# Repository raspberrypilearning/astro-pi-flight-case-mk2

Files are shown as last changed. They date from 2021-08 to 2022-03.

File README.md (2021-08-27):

# astro-pi-flight-case-mk2

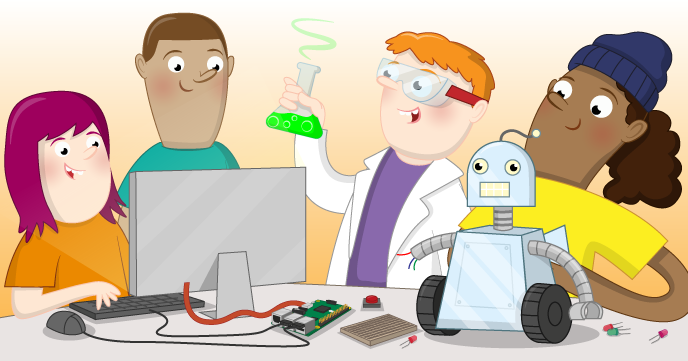
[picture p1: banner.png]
astro-pi-flight-case-mk2


Find the project online at [projects.raspberrypi.org/en/projects/astro-pi-flight-case-mk2](https://projects.raspberrypi.org/en/projects/astro-pi-flight-case-mk2)

## Resources
For project materials and solutions, see [en/resources](https://github.com/raspberrypilearning/astro-pi-flight-case-mk2/tree/master/en/resources) and [en/solutions](https://github.com/raspberrypilearning/astro-pi-flight-case-mk2/tree/master/en/solutions).

## Contributing
See [CONTRIBUTING.md](CONTRIBUTING.md)

## Licence
 See [LICENCE.md](LICENCE.md)

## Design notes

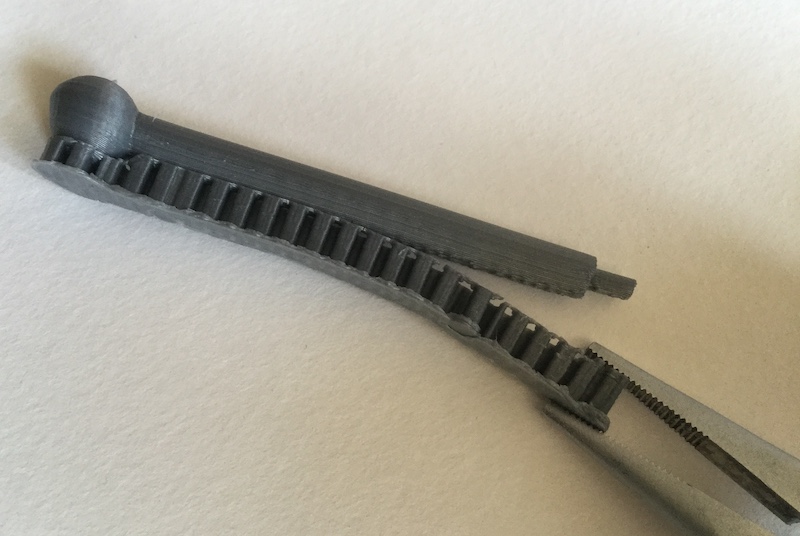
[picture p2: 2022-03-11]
en/images/leg_peel.jpg

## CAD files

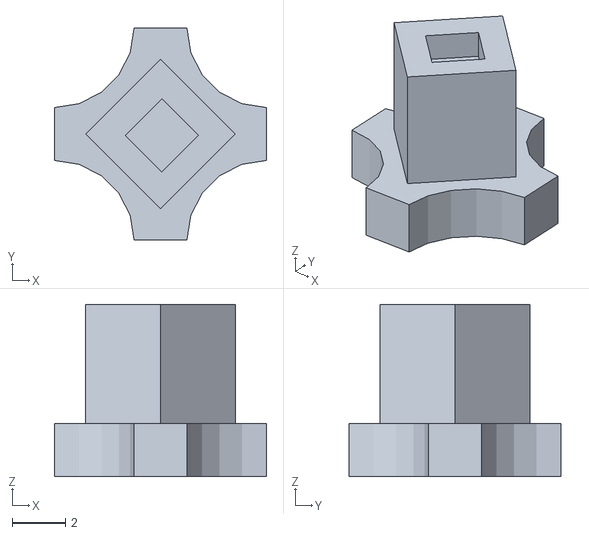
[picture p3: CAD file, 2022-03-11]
en/resources/Astro_Pi_Mark_II_joystick_cap.stl
8.00 x 8.00 x 6.50

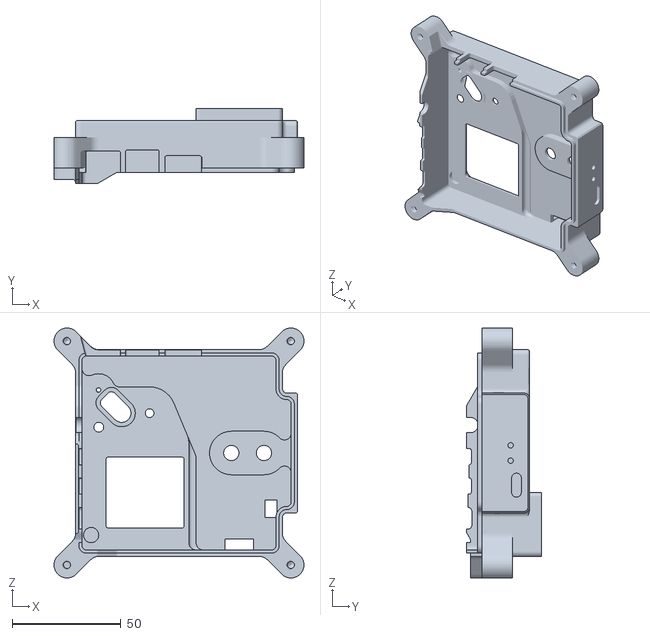
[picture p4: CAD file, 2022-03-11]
en/resources/Astro_Pi_Mark_II_upper_parallax_small_buttons_1.STL
114.8 x 34.7 x 114.8

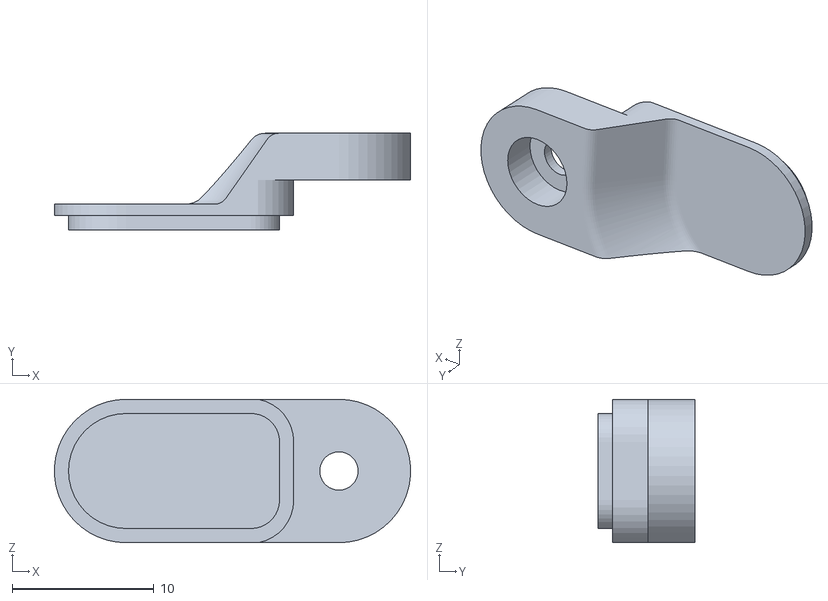
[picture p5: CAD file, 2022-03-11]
en/resources/Astro_Pi_Mark_II_window_1.STL
25.1 x 6.80 x 10.1

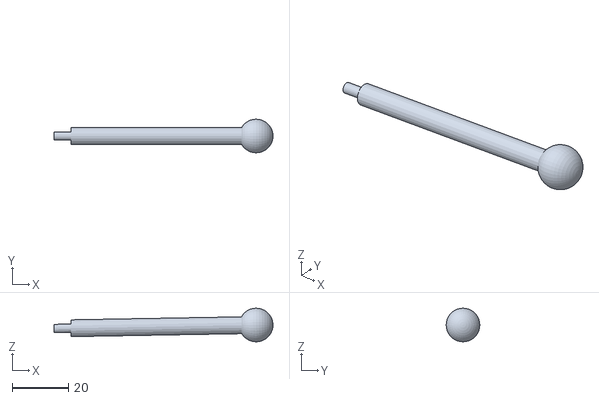
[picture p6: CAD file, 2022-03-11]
en/resources/Astro_Pi_Mark_II_leg.stl
78.0 x 12.0 x 12.0

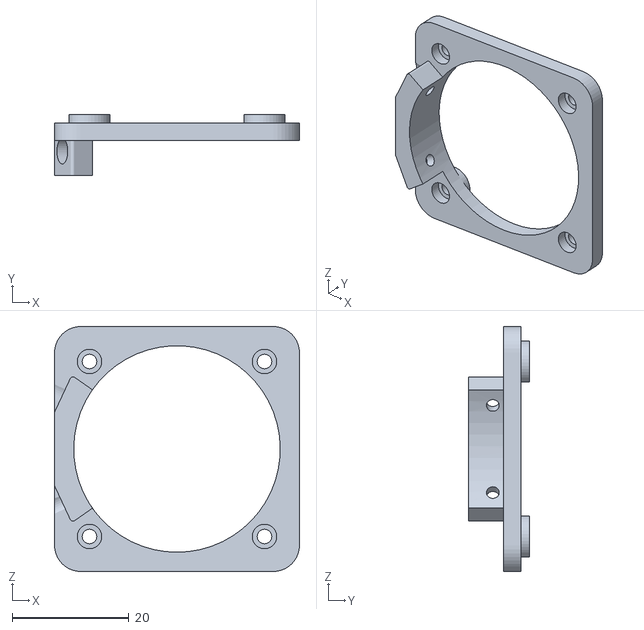
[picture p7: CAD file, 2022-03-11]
en/resources/Astro_Pi_Mark_II_camera_1.STL
42.0 x 10.4 x 42.0

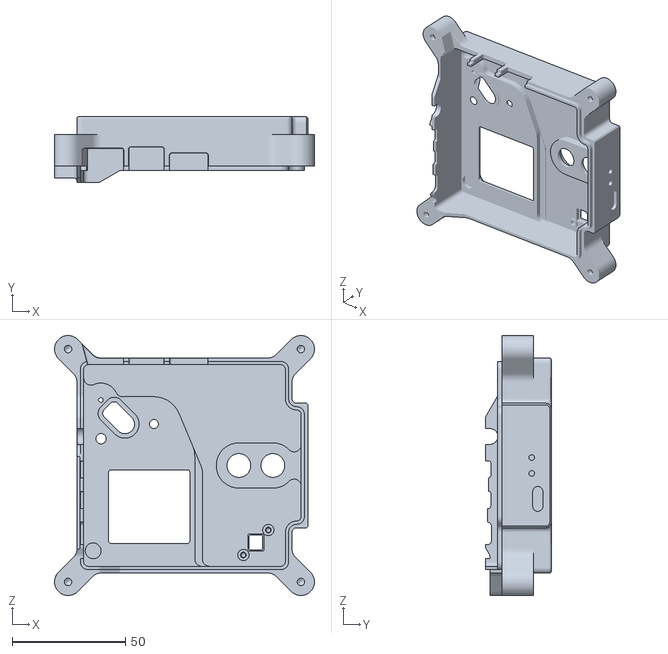
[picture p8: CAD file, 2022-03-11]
en/resources/Astro_Pi_Mark_II_upper_kemet_1.STL
114.8 x 29.0 x 114.8

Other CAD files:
en/resources/Astro_Pi_Mark_II_upper_parallax_1.STL
en/resources/Astro_Pi_Mark_II_upper_kemet_small_buttons_1.STL

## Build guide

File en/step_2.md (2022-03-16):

## Get the 3D files

The 3D files are in [STL](https://en.wikipedia.org/wiki/STL_%28file_format%29){:target="_blank"} format, which is widely used in 3D printing all over the world. If you import them using metric millimetres (mm), no scale adjustments will be required.

If you want to reproduce an authentic copy of the Astro Pi Flight Cases, you'll want to use one of the Kemet PIR sensors that is included on the ISS devices.

However, if you're wanting to build a Flight Case for your Astro Pi Mission Space Lab kit, then you may wish to use the modified STL files that have been produced to allow you to easily fit the Parallax PIR sensor (which is supplied in the kit) to the front panel. 

This means that there are four different options for the front panel: each sensor option has two possible button sizes. Make sure you download and print the right one for your project.

Please note that these STL files are licensed under a [Creative Commons Attribution-NonCommercial-ShareAlike 4.0 International License](https://creativecommons.org/licenses/by-nc-sa/4.0/).



--- task ---

Download each of these files and save them to a folder on your computer:

--- /task ---

**Part 1: Flight Unit front panel**

Here is the standard case front panel, like the ones on the ISS. It has a square hole in the top-right corner **for the Kemet PIR sensor**.

Version 1:  10mm button holes, for use with the buttons used on the ISS Flight Units

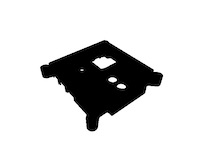
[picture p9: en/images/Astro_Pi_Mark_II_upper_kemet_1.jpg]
Astro_Pi_Mark_II_upper_kemet_1


[Astro_Pi_Mark_II_upper_kemet_1](resources/Astro_Pi_Mark_II_upper_kemet_1.STL) 

Version 2:  7mm button holes

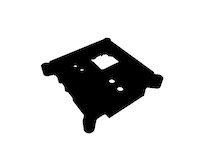
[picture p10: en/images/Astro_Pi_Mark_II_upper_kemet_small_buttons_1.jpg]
Astro_Pi_Mark_II_upper_kemet_small_buttons_1


[Astro_Pi_Mark_II_upper_kemet_small_buttons_1](resources/Astro_Pi_Mark_II_upper_kemet_small_buttons_1.STL) 
  
Here are the modified versions; these have a slot for mounting the larger **Parallax PIR sensor** that is supplied in the official Astro Pi Mission Space Lab entrant kits.

Version 3:  10mm button holes, for use with the buttons used on the ISS Flight Units

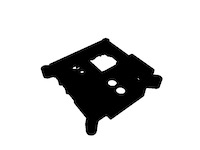
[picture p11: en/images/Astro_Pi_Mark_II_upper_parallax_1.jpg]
Astro_Pi_Mark_II_upper_parallax_1


[Astro_Pi_Mark_II_upper_parallax_1](resources/Astro_Pi_Mark_II_upper_parallax_1.STL) 

Version 4:  7mm button holes

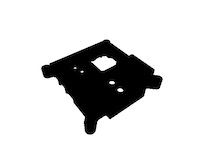
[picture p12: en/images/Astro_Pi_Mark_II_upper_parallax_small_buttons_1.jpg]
Astro_Pi_Mark_II_upper_parallax_small_buttons_1


[Astro_Pi_Mark_II_upper_parallax_small_buttons_1](resources/Astro_Pi_Mark_II_upper_parallax_small_buttons_1.STL) 
  
**Part 2: Flight Unit base**

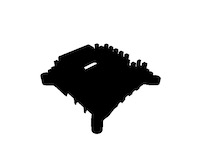
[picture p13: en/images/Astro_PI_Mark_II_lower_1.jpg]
Astro_PI_Mark_II_lower_1


[Astro_PI_Mark_II_lower_1](resources/Astro_PI_Mark_II_lower_1.STL) 

**Part 3: High-Quality Camera sensor mount**

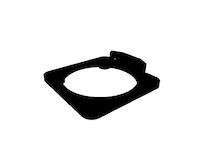
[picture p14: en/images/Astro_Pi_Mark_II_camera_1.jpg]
Astro_PI_Mark_II_camera_1


[Astro_Pi_Mark_II_camera_1](resources/Astro_Pi_Mark_II_camera_1.STL) 

**Part 4: Light sensor window**

The windows on the ISS Flight Units are printed using a transparent resin. This may be difficult to reproduce without a more specialised printer. If you're building a Flight Unit to use with an Astro Pi Mission Space Lab entry kit, we suggest you omit the window so that you can get useful data from the Sense HAT's light sensor. 

If you don't need to use the light sensor, or have an older Sense HAT that doesn't have a light sensor, you could print the window using the same colour filament as the rest of the case, or maybe use a different colour for a custom look. 

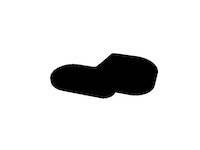
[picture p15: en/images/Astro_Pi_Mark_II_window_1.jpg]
Astro_PI_Mark_II_window_1


[Astro_Pi_Mark_II_window_1](resources/Astro_Pi_Mark_II_window_1.STL) 

**Part 5: Joystick cap**

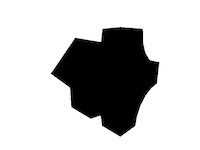
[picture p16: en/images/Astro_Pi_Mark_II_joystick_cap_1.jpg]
Astro_PI_Mark_II_joystick_cap_1


[Astro_Pi_Mark_II_joystick_cap_1](resources/Astro_Pi_Mark_II_joystick_cap.stl)

Note that this joystick cap may need some slight adjustments due to the nozzle size and layer height of your printer. If you have difficulty with fitting it onto the stump of the Sense HAT joystick, then try using a layer height of 0.1mm as opposed to 0.15mm. Because the part is so small, it is also prone to heat warping. The cap was designed using [Tinkercad and you can remix the design](https://www.tinkercad.com/things/9LQoVurYOeM) to precisely adjust the dimensions so that the cap produced by your printer correctly fits the Sense HAT's joystick rod.

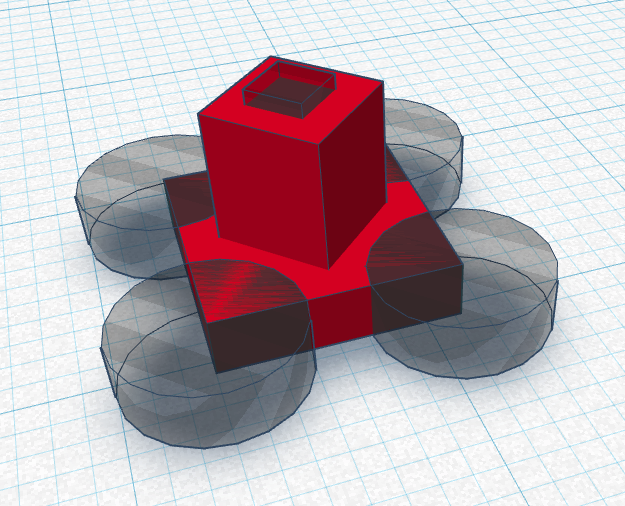
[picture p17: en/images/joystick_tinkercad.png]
Screenshot showing the joystick cap part rendered with Tinkercad.


**Part 6: Legs**

To protect the lens and any window surface against which the Astro Pi may be placed onboard the ISS, the Flight Unit has four removable titanium legs with plastic balls on the end. 

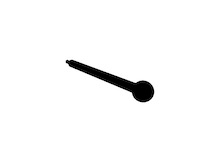
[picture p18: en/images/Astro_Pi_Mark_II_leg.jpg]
Astro_PI_Mark_II_leg


[Astro_Pi_Mark_II_leg](resources/Astro_Pi_Mark_II_leg.stl)

This part is also available for [tweaking and remixing on Tinkercad](https://www.tinkercad.com/things/flDuNtFK9Zh).

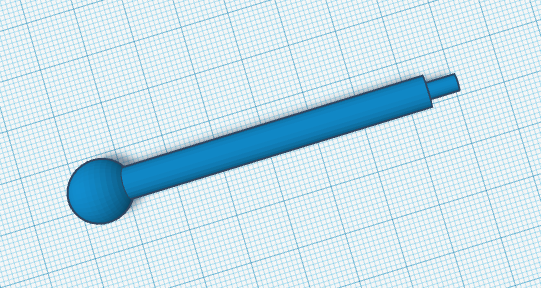
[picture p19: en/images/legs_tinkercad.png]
Screenshot showing the leg part rendered on Tinkercad.


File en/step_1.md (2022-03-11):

## Introduction

The Astro Pi Flight Case is one of the most sought-after cases in the history of the Raspberry Pi. The original Mark I hardware Flight Units have been in operation on the International Space Station (ISS) since 2015. In 2021, new, upgraded Astro Pis were sent as replacements. With the inclusion of a more powerful Raspberry Pi, new sensors, and the Raspberry Pi High-Quality Camera, a new Flight Case design was required. 

In this resource, you will learn how to 3D print your own Astro Pi Mark II Flight Case and install the Astro Pi hardware inside it. You’ll then have your very own Astro Pi Flight Unit, identical in almost every way to the new ones that are now operational on the ISS.

You don't have to follow every step exactly as it is described in this guide, which is intended to provide a reliable set of instructions for someone who would like to produce a replica case. There are often many different ways to tackle projects like this, so if you have another preferred technique, or think that something should be done in a different way, you should go ahead and try an alternative approach. This is particularly true for the 3D printing part of the project: there are lots of different 3D printers and filaments and you should expect to have to modify some of the steps in order to take these differences into account. Please note that this is a complex project and that you should expect to have to tweak your process for best results. Be prepared for print jobs that don’t produce the best possible parts first time. 

### What you will make

--- no-print ---
Here are some examples of how your finished 3D-printed Astro Pi Flight Cases might look:

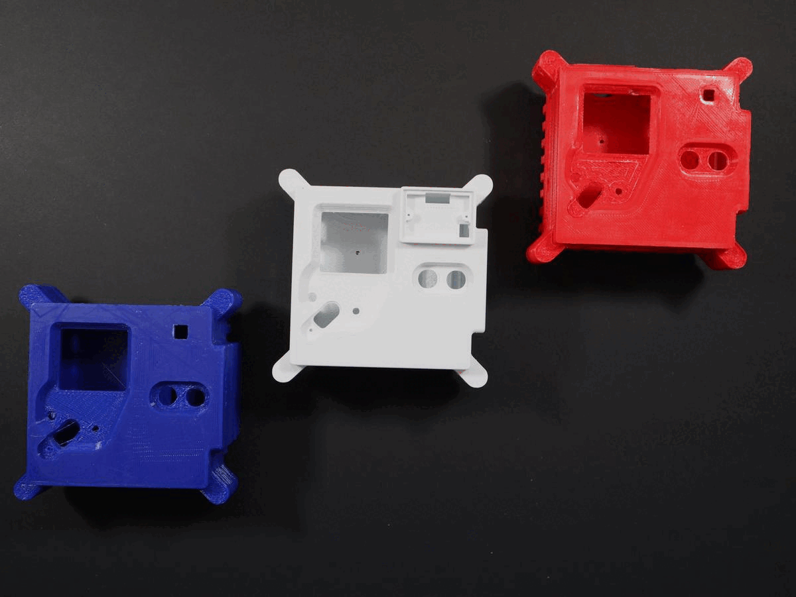
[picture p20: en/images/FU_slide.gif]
A series of images showing several 3D-printed Flight Cases, with different colours, buttons, and one with legs.


--- /no-print ---

--- print-only ---
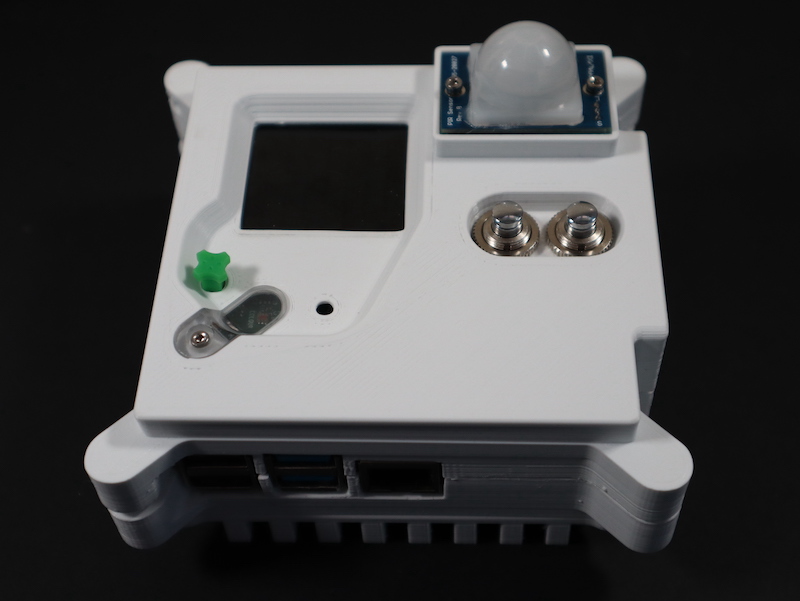
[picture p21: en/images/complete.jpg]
A photo of the completed Flight Case.

--- /print-only ---

--- collapse ---
---
title: What you will need
---
### Hardware

+ [Raspberry Pi 4](https://www.raspberrypi.com/products/raspberry-pi-4-model-b/) and SD card
+ [Raspberry Pi High-Quality Camera](https://www.raspberrypi.com/products/raspberry-pi-high-quality-camera/) 
+ [Raspberry Pi Sense HAT](https://www.raspberrypi.com/products/sense-hat/)
+ 2 Push buttons (either 10mm diameter thread or 7mm — see below)
+ [Kemet](https://uk.farnell.com/kemet/ss-430l-w/pir-sensor-5m-37deg-28deg-5-5vdc/dp/3027688) or [Parallax](https://www.parallax.com/product/pir-sensor-with-led-signal/) Passive Infrared (PIR) sensor (as supplied in the official Mission Space Lab kits)
+ If using the Kemet PIR sensor, you'll also need the [right cable](https://www.digikey.co.uk/en/products/detail/jst-sales-america-inc/A05SR05SR30K152B/6708507)
+ If using the Parallax PIR sensor, you'll need a three-segment electrical connector block
+ M2.5/M2.5 × 11mm × 5mm M/F threaded hexagon spacers 
+ M2.5/M2.5 × 10mm × 5mm M/F threaded hexagon spacers 
+ [26-Pin tall header](https://thepihut.com/products/stacking-header-for-raspberry-pi-2x13-extra-tall)
+ M2.5 × 6mm full thread cap head screws (DIN 912) 
+ M2 X 16mm cap head screws (DIN 912) 
+ M2 Hexagon Nuts (DIN 934) - Stainless Steel 
+ M4 × 12mm full thread cap head screws (DIN 912)
+ M2 × 8mm full thread cap head screws (DIN 912) 
+ 7 Short (approx. 120mm) jumper wires, with one end F
+ Some 2mm diameter heat shrink tubing
+ A 90 × 50mm strip of [Rosco 98 medium grey filter film](https://us.rosco.com/en/products/filters/r98-medium-grey) 

If you want to buy the [exact buttons](https://www.mouser.co.uk/datasheet/2/26/pusbutton-switches-serie-10400-1519227.pdf) used in the Astro Pi Flight Unit, the details are below. However, they are expensive — that's because they're designed to survive an enormous number of clicks before wearing out, a feature that is necessary for a five-year space mission.

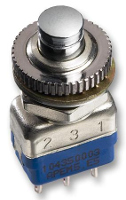
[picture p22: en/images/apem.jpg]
Astro Pi actual button.


- Manufacturer: APEM
- Manufacturer Part No: 104350003

If you want to use different (cheaper) buttons, then go ahead. We have two different versions of the top panel of the flight unit, one for 10mm buttons, one for 7mm. You should decide on your choice of buttons before printing your case!

### Additional requirements

+ Access to a 3D printer. Many schools now have their own, or you might be able to find one at your local [Makerspace](http://www.hackspace.org.uk/){:target="_blank"}. You can also find local 3D printing services through the [3D Hubs website](https://www.3dhubs.com/){:target="_blank"}.

You’re also going to need the following tools:

+ 1.5mm Allen key
+ 2.5 Allen key
+ Small pair of pliers
+ Craft knife or scalpel
+ Sandpaper
+ Scissors
+ Sticky tape
+ Wire strippers
+ Wire cutters
+ Soldering iron and solder (if you've never soldered before, have a look at [this video](https://www.raspberrypi.com/news/getting-started-soldering/) for some tips) 
+ Hot air gun

### Software

+ Raspberry Pi OS

### Downloads

+ [Self test software](resources/selftest.zip)

--- /collapse ---

--- collapse ---
---
title: What you will learn
---

+ Techniques to 3D print irregular shapes
+ How to connect electronics to the Raspberry Pi computer using GPIO pins

--- /collapse ---

--- collapse ---
---
title: Additional information for educators
---

If you need to print this project, please use the [printer-friendly version](https://projects.raspberrypi.org/en/projects/projectName/print){:target="_blank"}.

--- /collapse ---

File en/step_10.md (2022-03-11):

## Assemble the case

Once you're happy that the internals of the case are complete, you can proceed to the final assembly stage.

--- task ---

Cut a strip of the grey Rosco filter material 45mm × 90mm and fold it in half. Use two small pieces of tape to attach it to the inside of the top panel, over the LED matrix window. Make sure none of the tape is visible from the outside.

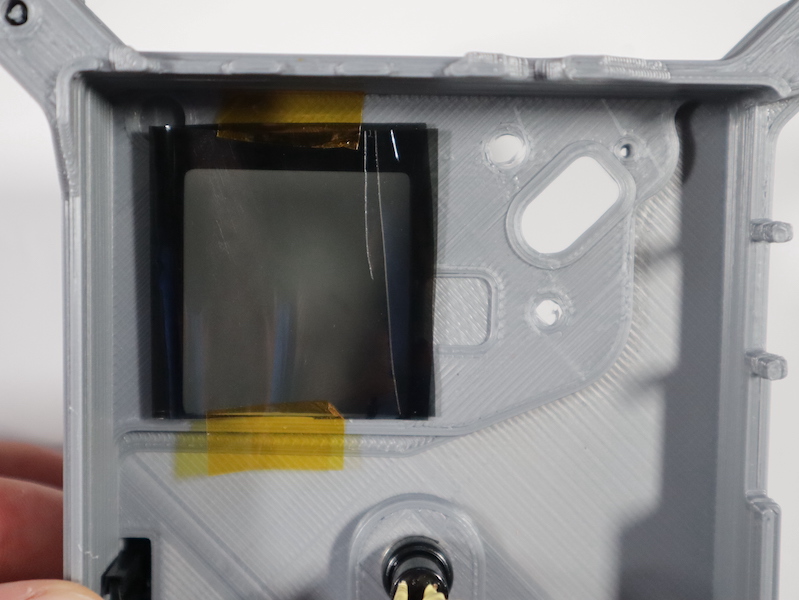
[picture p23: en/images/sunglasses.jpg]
Photo showing the LED matrix filter held in place with two small pieces of tape.


--- /task ---

--- task ---

Take the top panel and gently tuck the wires into the space on the right of the Raspberry Pi as neatly as you can.

--- /task ---

--- task ---

Place the top panel on top of the bottom case part.

--- /task ---

--- task ---

Screw the two case halves together with M4 × 12mm screws.

--- /task ---

--- task ---

Install your 3D-printed joystick cap by pressing it onto the Sense HAT joystick. You will probably need to use glue to keep it in place, but only apply the glue once you've tested everything and are happy that it all works. The Astro Pis on the ISS use a 3D-printed cap too!

--- /task ---

--- task ---

Fit the four legs into the holes on the rear panel. You may need to use glue to keep them in place, or you can try adjusting the dimensions of the part to optimise the fit for parts printed on your specific printer. 

--- /task ---

Your Astro Pi Flight Unit is almost complete — the last thing to do is to add the colour sensor window. Fit this into the slot and attach it with a M2.5 × 6mm screw.

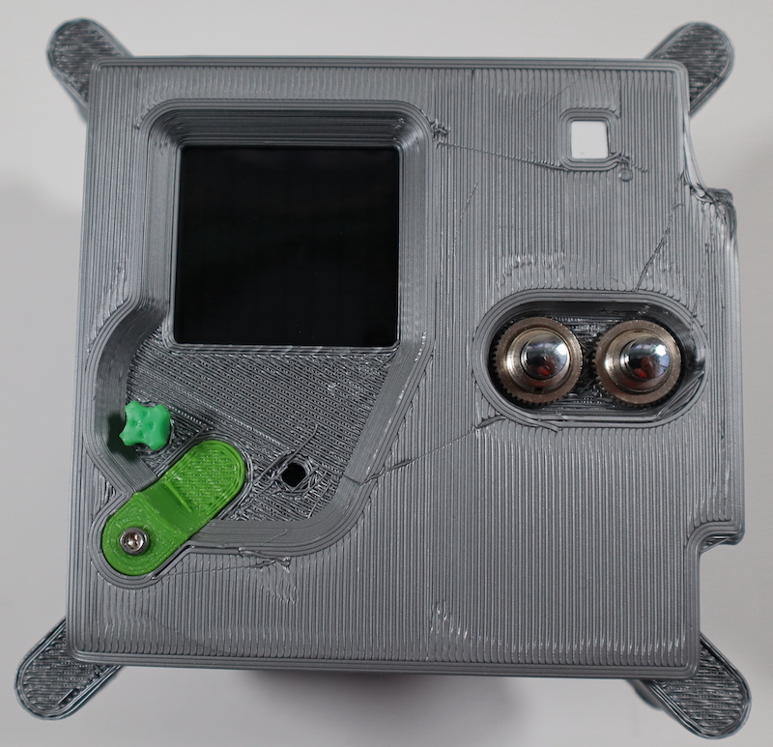
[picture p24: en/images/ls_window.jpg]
A photo of a 3D-printed Flight Unit with a green joystick cap and light sensor window.


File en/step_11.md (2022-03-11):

## Test the hardware

--- task ---

Once you have assembled the Astro Pi, start it up with a monitor, keyboard, and mouse connected.

--- /task ---

For use on the ISS, we created a program that performs a test of the hardware to make sure everything is working. You can download a version of this software to run on your 3D-printed Astro Pi to check your wiring.

--- task ---
[Download the software](resources/selftest.zip) and then open a terminal window and enter these commands:

```bash
unzip selftest.zip
```

--- /task ---

--- task ---
Then run the tests:

```bash
cd selftest
python3 selftest.py --timeout 20
```
A series of tests will begin, some run autonomously whereas others are interactive and require a user to physically manipulate the Astro Pi unit when prompted. If you want longer to complete each test, increase the value supplied as the `timeout` parameter.

Initially, some of the LEDs on the matrix will light up, indicating the outcomes of the diagnostic tests. Then, a series of icons will be displayed to indicate which interactive test is active.

First will be the humidity sensor test. 

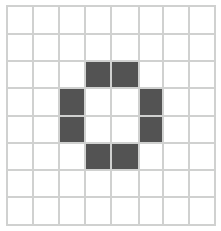
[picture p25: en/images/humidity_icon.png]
The icon for the interactive humidity test: an open central square made up of 8 illuminated LEDs.


When you see this icon in red, blow on the hole to the right of the light sensor window. If the sensor is working (and you've provided sufficiently moist puff), the icon should turn green.

Next is the gyroscope test. 

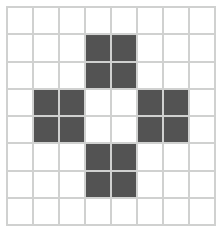
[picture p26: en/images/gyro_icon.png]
The icon for the interactive gyroscope test: a cross shape made up of 4 squares of 4 illuminated LEDs.


When you see this icon in red, tilt the Astro Pi Flight Unit towards any of the four directions, in any order, until all four squares that make up the icon have turned green.

Then there is the accelerometer test. 

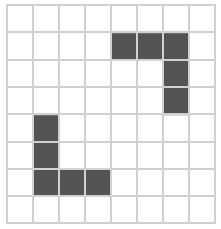
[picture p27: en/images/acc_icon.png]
The icon for the interactive accelerometer test: two diagonally opposed chevrons each made up of 5 illuminated LEDs.


When you see this icon in red, shake the Astro Pi Flight Unit until the icon has turned green.

Next up is the motion sensor test. 

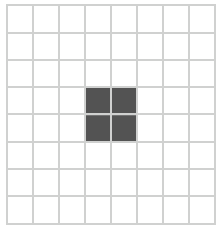
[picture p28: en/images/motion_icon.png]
The icon for the interactive motion sensor test: a small solid square of 4 illuminated LEDs.


When you see this icon in red, wave your hand in front of the Astro Pi Flight Unit until the icon has turned green.

The penultimate test is for the joystick. 

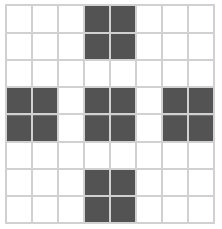
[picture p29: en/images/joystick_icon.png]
The icon for the interactive joystick test: 5 squares of 4 illuminated LEDs in a cross shape.


When you see this icon in red, move the joystick in any of the four directions, in any order. Then press the joystick (like a button). All elements of the icon should turn green.

The final test is for the two buttons. 

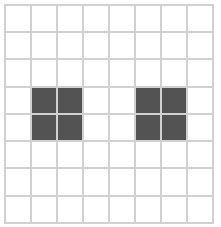
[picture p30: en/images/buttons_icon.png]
The icon for the interactive button test: two side by side squares of 4 illuminated LEDs each.


When you see this icon in red, press buttons A and B, in any order. Both squares of the icon should turn green.
--- /task ---

Once the program has finished, the overall status will be displayed on the LED matrix. 

A green pixel indicates that the test was successful.

A teal pixel shows that an interactive test was not successfully completed before the specified timeout period expired. 

A red pixel is used to identify a test which failed. 

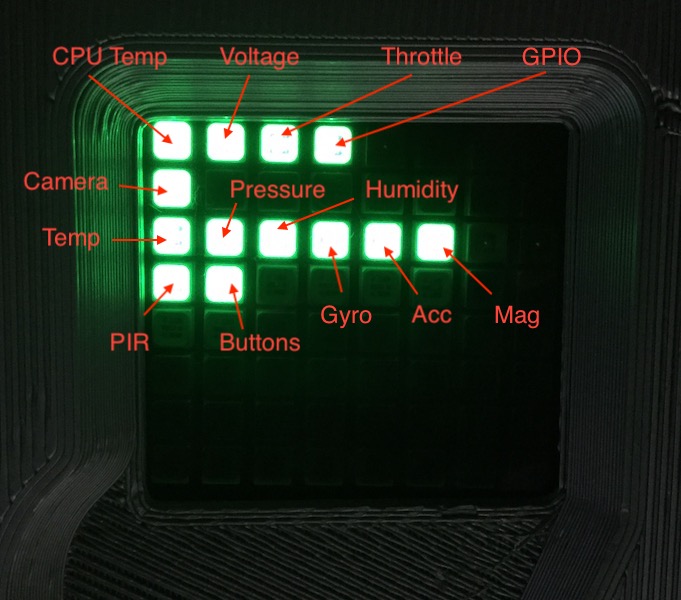
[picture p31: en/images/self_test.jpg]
The LED matrix showing the results of a self-test, with 15 illuminated green LEDs.


| Test  |  Description | 
|---|---|
| CPU Temp  | Is the Raspberry PI's CPU temperature within safe levels? | 
| Voltage | Are the block voltages within a sensible range? | 
| Throttle  | Has an undervoltage condition occurred? | 
| GPIO  |  Are the GPIO pins working? | 
| Camera | Is the camera detected?|

The other tests are related to the Sense HAT sensors, buttons, and PIR sensor. 

For more details about each test, have a look at the comments for each function in functions.py, and the Raspberry Pi documentation for the [vcgencmd command](https://www.raspberrypi.com/documentation/computers/os.html#vcgencmd). 

If any of the tests fail, look at whatever messages are displayed in the Terminal for clues as to what may have gone wrong. If the motion sensor or buttons test fails, check that you have connected the jumper wires to the correct GPIO pins as described earlier. If you have chosen different pins for the PIR sensor or buttons, you don't need to adjust your wiring, you can change the pin assignments in the `test_buttons` and `test_motion` functions in the functions.py file.

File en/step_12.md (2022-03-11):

## Challenge: Improve your case

Here are some further ideas for customising your case:

- Use metallic grey spray paint
- Use sandpaper to create the matte finish that the bead-blasted aluminium flight cases have
- Engrave decals into the case
- Use different filament colours for each part
- Design a bespoke joystick cap

The STL files are released under the Creative Commons attribution [licence](https://creativecommons.org/licenses/by-nc-sa/4.0/){:target="_blank"}, so you are welcome to remix and adapt the designs for non-commercial purposes, as long as you credit us and license your new creations under the identical terms. Please note that GitHub has a great [STL viewer](https://github.com/blog/1465-stl-file-viewing){:target="_blank"}, as well as a [3D file diff](https://github.com/blog/1633-3d-file-diffs){:target="_blank"}, which could be useful for tracking your changes.

By far the greatest benefit of owning a replica Astro Pi Flight Unit is the ability to prototype and test code that could be run on the International Space Station as part of Mission Space Lab. Head over to the [Astro Pi website](https://astro-pi.org/){:target="_blank"} now to get involved!

Show us your finished case by tweeting pictures of them to [@astro_pi](https://twitter.com/astro_pi){:target="_blank"} and [@RaspberryPi_org](https://twitter.com/Raspberry_Pi){:target="_blank"}.

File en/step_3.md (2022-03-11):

## Print each part

**It is important that you observe the correct safety procedures specified in the data sheet for your specific 3D printer.**

Potential hazards include:

- Hot surfaces and thermoplastics (print head block and bed)
- Moving parts (printing assembly)

We tried this project on a range of 3D printers including:

 - [Cel Robox](https://cel-uk.com/shop/roboxdual/){:target="_blank"}.
 - [Lulzbot Taz 6](https://www.lulzbot.com/store/printers/lulzbot-taz-6)
 - [Lulzbot Mini](https://www.lulzbot.com/store/printers/lulzbot-mini)

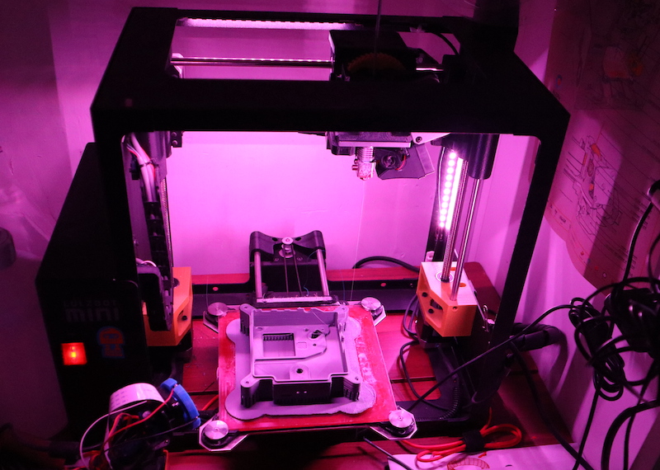
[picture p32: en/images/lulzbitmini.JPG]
Photo showing a 3D-printed Flight Unit top panel sitting on the bed of a Lulzbot Mini printer.


We mainly used PLA (polylactic acid) filament in our prints, but we have also printed test cases using ABS (acrylonitrile butadiene styrene).  There are many different 3D printer models, so you should make any necessary adaptations to the instructions in order to get the best results from your particular machine.  

All parts except for the joystick cap will need to be printed with support scaffolding as there is no completely flat surface with any orientation. For most printers, you may also wish to add a raft as this may make it much easier and quicker to remove the scaffolding, especially from the heat sink fins on the Flight Case base. It also prevents heat warping and can be useful for the joystick and leg parts. It will, however, increase the print time. 

--- task ---

The STL files have been generated from the original CAD designs used to make the Mark II aluminium Flight Cases on the International Space Station. 

Depending on your printer and how you use it, you may be able to load these files into a software application that can directly control the hardware and will manage the entire process for you. In the image below, you can see the STL file for the camera mount loaded directly into the Cel Robox application.

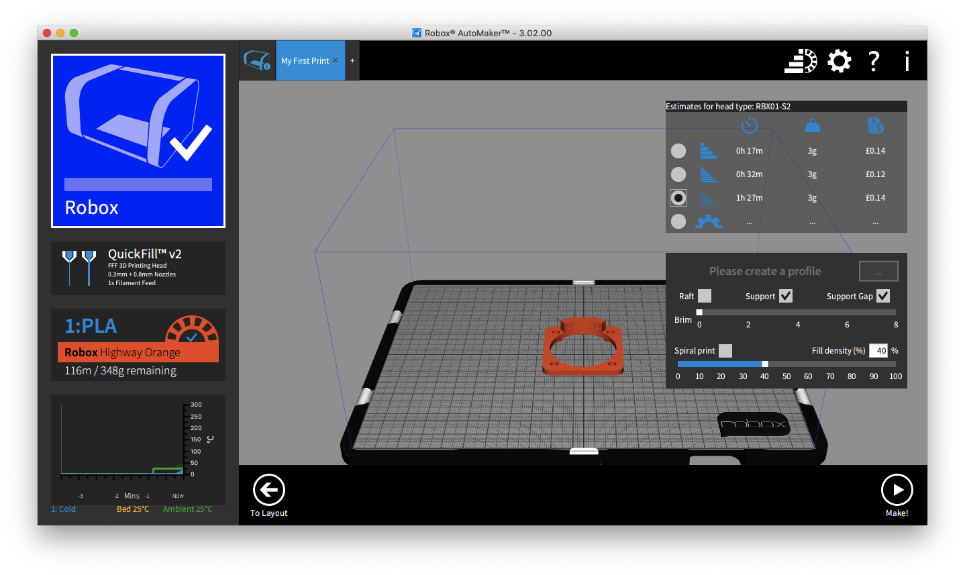
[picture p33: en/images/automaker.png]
Screenshot from Cel Robox printer showing the imported Flight Unit base on the virtual printer bed.


Or if you use a web interface or other client software such as [Octoprint](https://octoprint.org/) to control a [FDM/FFF printer](https://en.wikipedia.org/wiki/Fused_filament_fabrication#Fused_deposition_modeling), you may need to use separate slicing software like [Cura](https://github.com/Ultimaker/Cura), which will convert the model into a series of thin layers to produce a G-code file containing instructions. The image below is from the popular Cura slicing application.

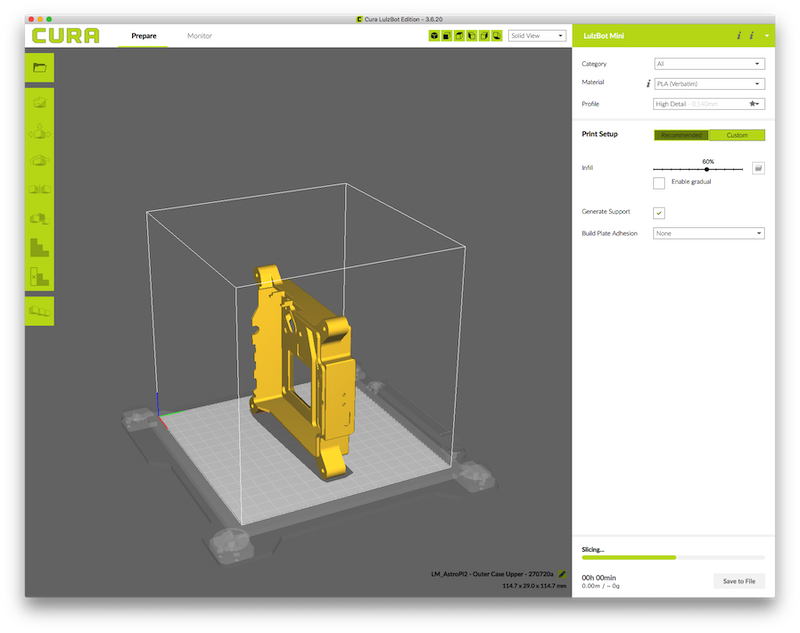
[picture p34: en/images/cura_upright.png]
Screenshot showing an example of the Cura slicing software with a front part standing upright.


--- /task ---

--- task ---
This G-code file can then be printed via the client software, which will load the G-code and use it to instruct the printer during the 3D printing process.

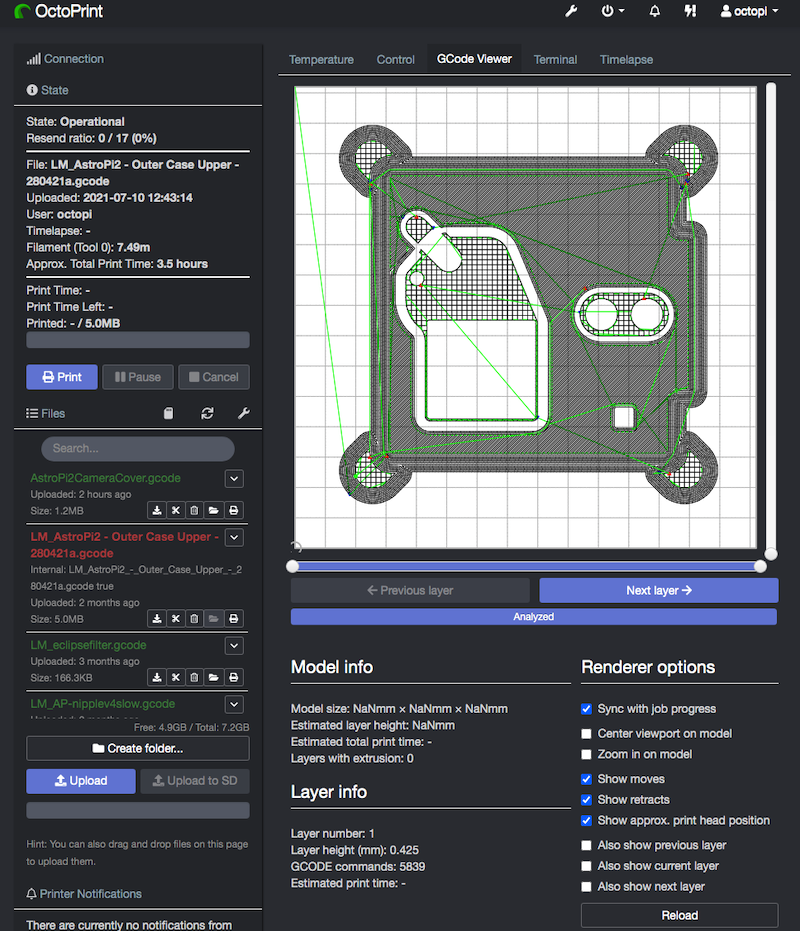
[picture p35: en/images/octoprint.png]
Screenshot showing an example of the Octoprint web interface, which displays the imported Flight Unit base in the G-code viewer.


To get a nice finish, we recommend you print on a high detail setting; this is usually a number specified in [microns](https://en.wikipedia.org/wiki/Micrometre){:target="_blank"} in the 3D printer software. The lower this number is, the more precise the model will be. Please also be aware that precise prints take longer and, for the models you're going to make, each piece can take up to **ten hours** to complete. Make sure you have enough filament.

Having said that, our test cases were also printed using the default "medium quality" settings for the printers and they look fine. 

--- /task ---

--- task ---

Whether you're using an application that can work directly from the STL file, or creating a G-code file using slicing software, you should make sure you adjust the orientation of the parts on the virtual printer bed so that they lay flat as shown below. This will minimise scaffolding and rafting.

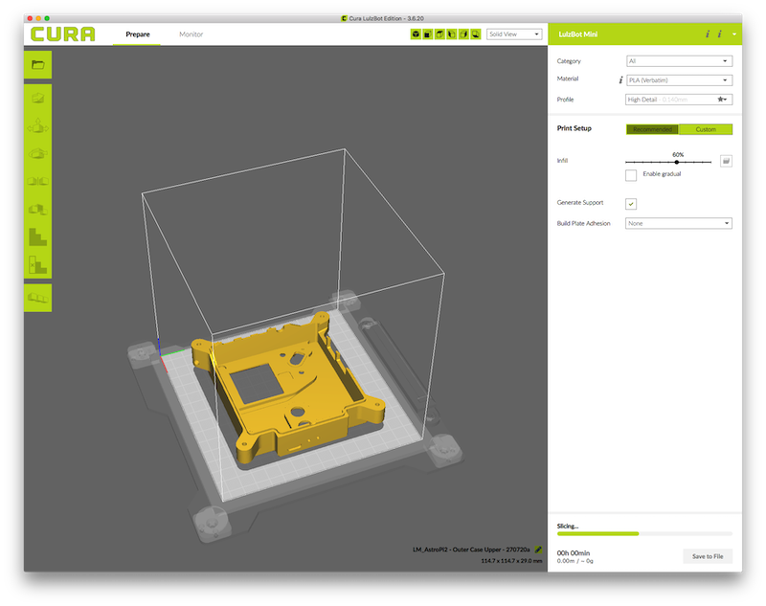
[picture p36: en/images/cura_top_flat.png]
Screenshot showing an example of the Cura slicing software with a front part laying flat and face down.


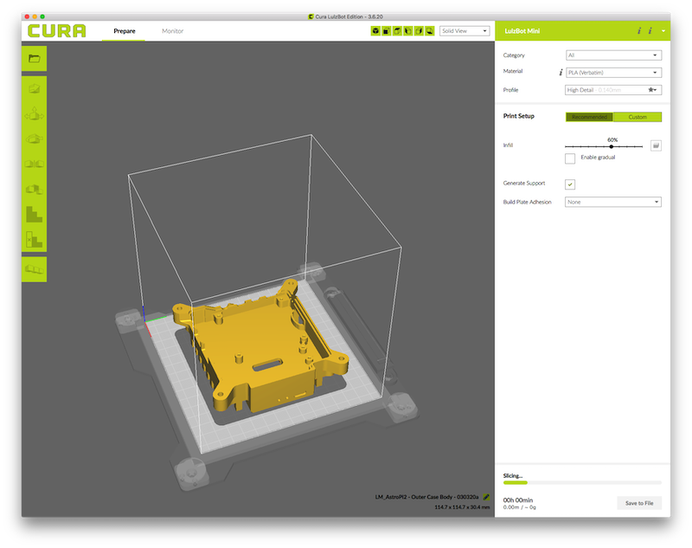
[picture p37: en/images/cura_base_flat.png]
Screenshot showing an example of the Cura slicing software with a base part laying flat and face down.


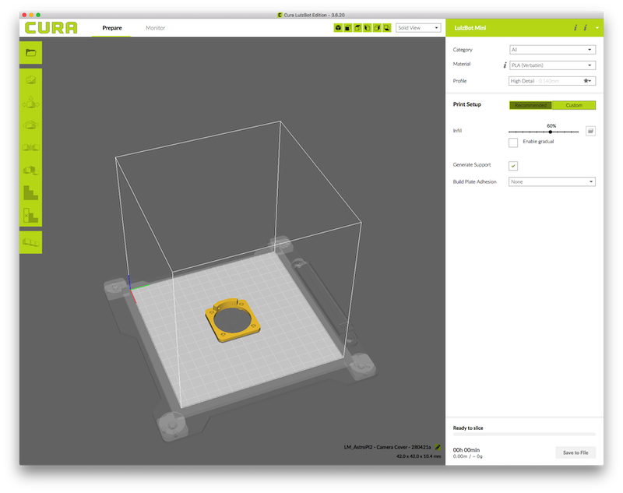
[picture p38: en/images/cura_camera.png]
Screenshot showing an example of the Cura slicing software with the camera mount part laying flat and face down.


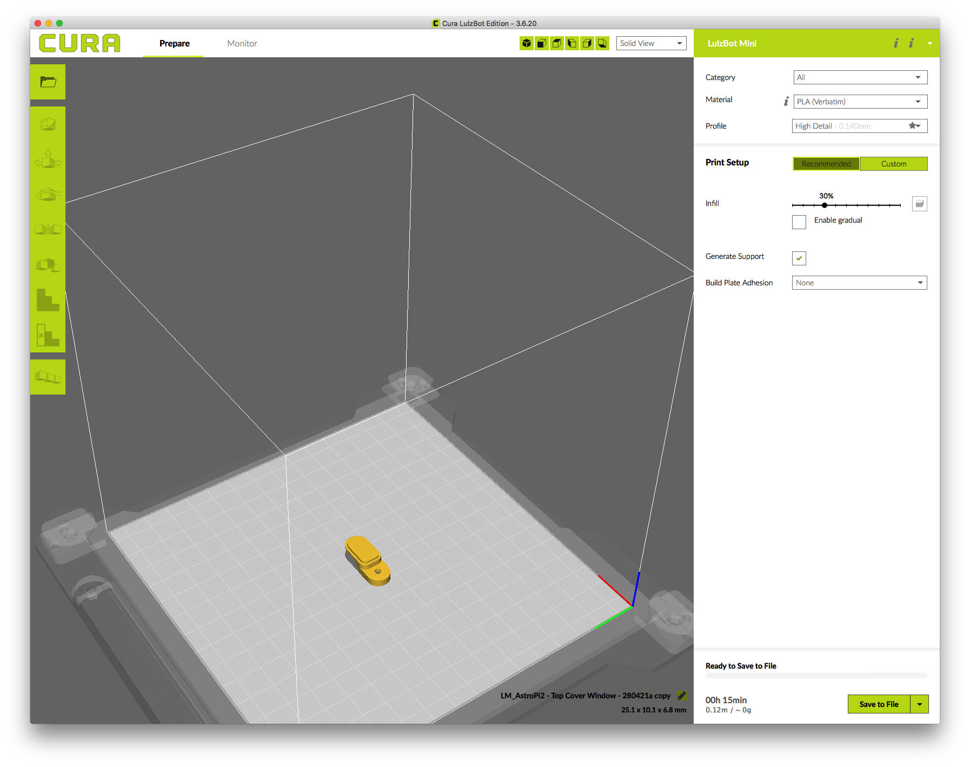
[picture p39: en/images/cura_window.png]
Screenshot showing an example of the Cura slicing software with the light sensor window laying flat and face down.


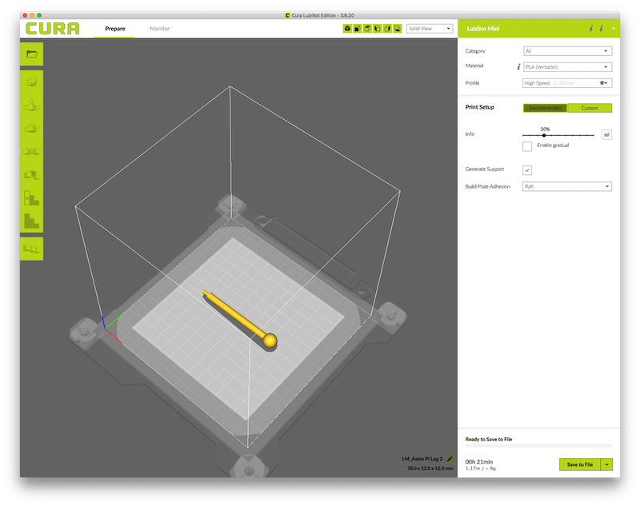
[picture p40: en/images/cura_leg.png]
Screenshot showing an example of the Cura slicing software with the leg part laying flat and face down.


--- /task ---

--- task ---

Once you've checked all the various options, start your print job. Remember that some of the parts may take several hours to complete and use a fair amount of material. So make sure you have enough time and filament available.

--- /task ---

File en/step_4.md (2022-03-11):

## Remove the scaffolding

When the parts have finished printing, try to remove them from the bed of your printer, keeping the raft attached. Leave the print to cool down completely to room temperature before you touch it.

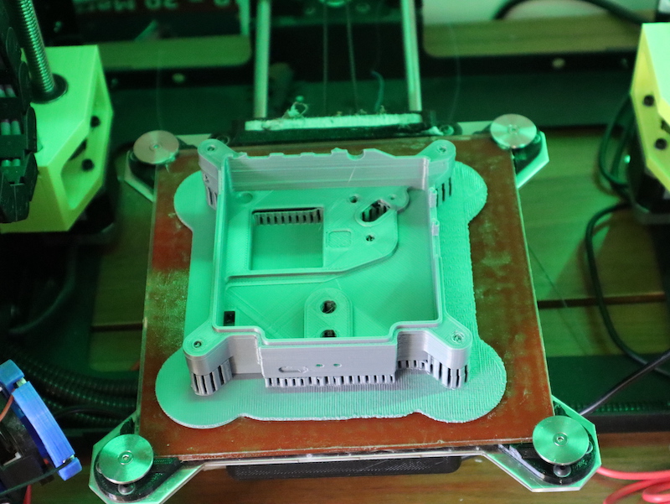
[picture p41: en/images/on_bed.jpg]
Photo of a complete top panel still on the printer bed with its raft attached.


To keep the model structurally sound while printing, your 3D printer will create what's called scaffolding and rafting to prevent the hot thermoplastics from bending or sagging. 

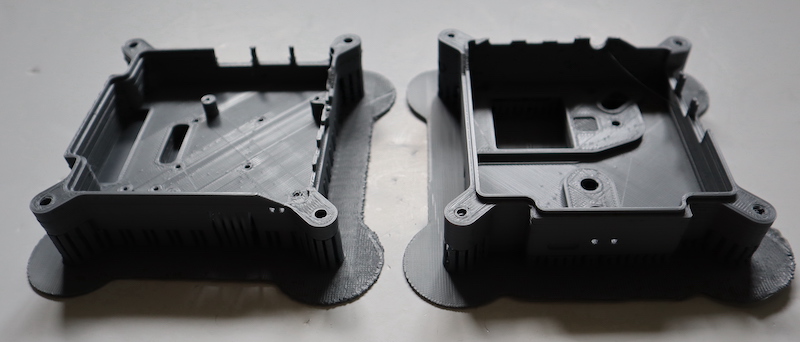
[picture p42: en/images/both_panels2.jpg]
Photo of two grey 3D-printed panels side by side.


### Flight Case front panel

If you've printed this part with a raft, you should be able to separate the raft from the base and carefully peel it away so that it also takes the scaffolding with it. 

--- task ---

Start by freeing the scaffolding at the corners by using a small pair of pliers.

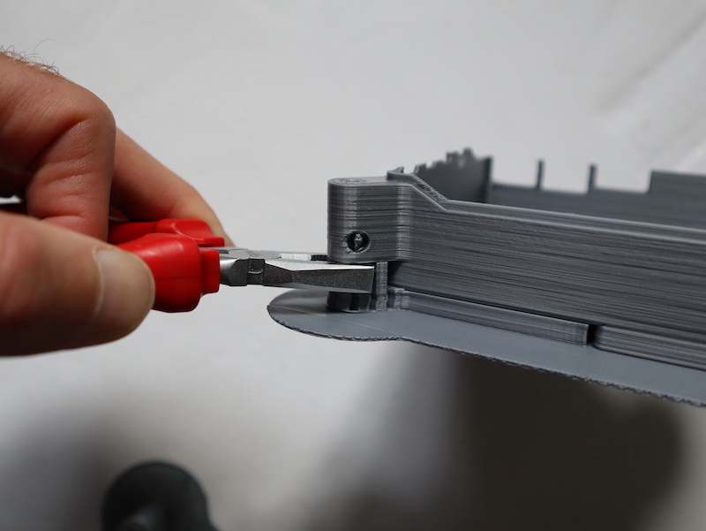
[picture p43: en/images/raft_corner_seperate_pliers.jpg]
Photo of the silver 3D-printed front panel, showing pliers being used to separate the corner scaffolding.


--- /task ---

--- task ---
Then, use your fingers to prise the raft from the base. You may need to carefully slip a craft knife blade into the gap to get things started. 

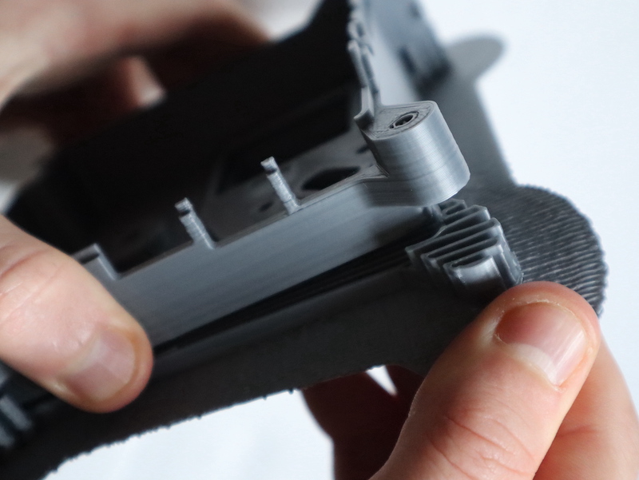
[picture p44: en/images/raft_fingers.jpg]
Photo of the silver 3D-printed front panel, showing the separation of the raft from the corner scaffolding.


--- /task ---

--- task ---
Begin to peel back the raft, checking that the scaffolding is being removed with it.

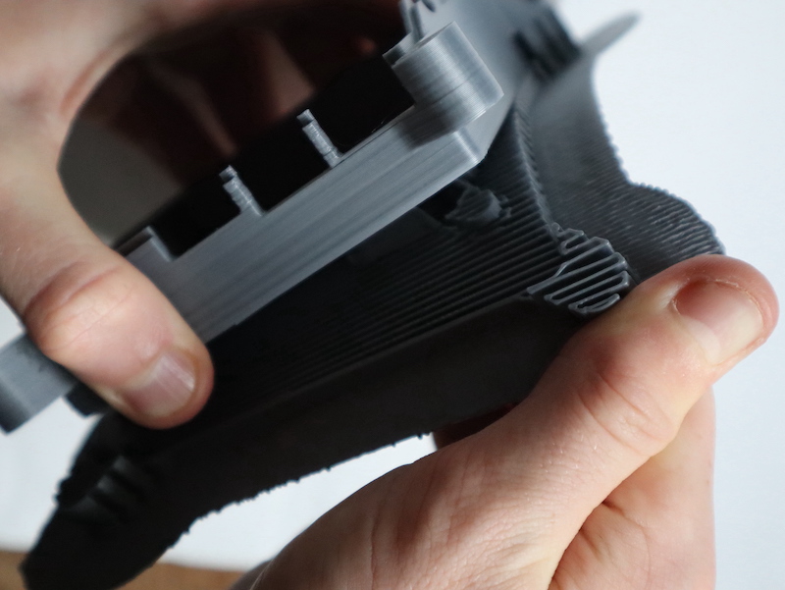
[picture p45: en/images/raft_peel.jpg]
Photo of the silver 3D-printed front panel, showing the raft being peeled away.


Continue slowly peeling the raft away.

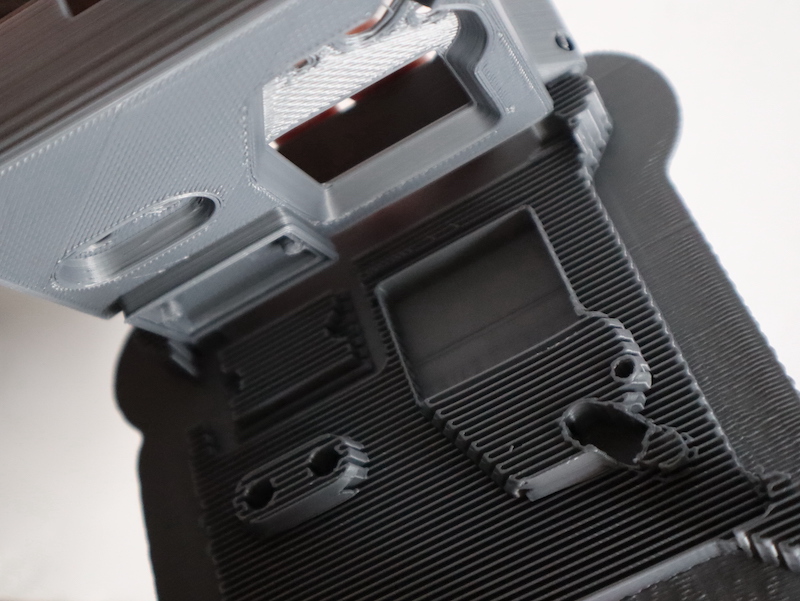
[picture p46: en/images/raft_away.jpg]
Photo of the silver 3D-printed front panel, showing the raft having been completely removed.


--- /task ---

If you didn't use a raft for you print, there are three main scaffolding areas to deal with. 

--- task ---

Start with the area beneath the LED matrix window. You should be able to slide a craft knife or small screwdriver under the lip of the scaffold and peel it away.

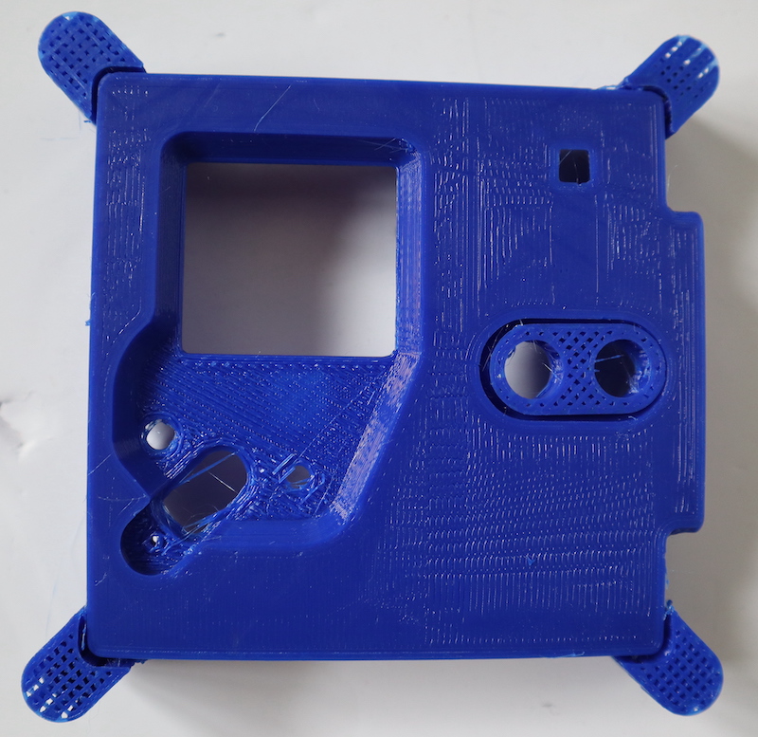
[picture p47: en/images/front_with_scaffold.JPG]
Photo showing the scaffolding from beneath the LED matrix window being peeled off.


--- /task ---

--- task ---

Then do the same thing with the region around the button holes. 

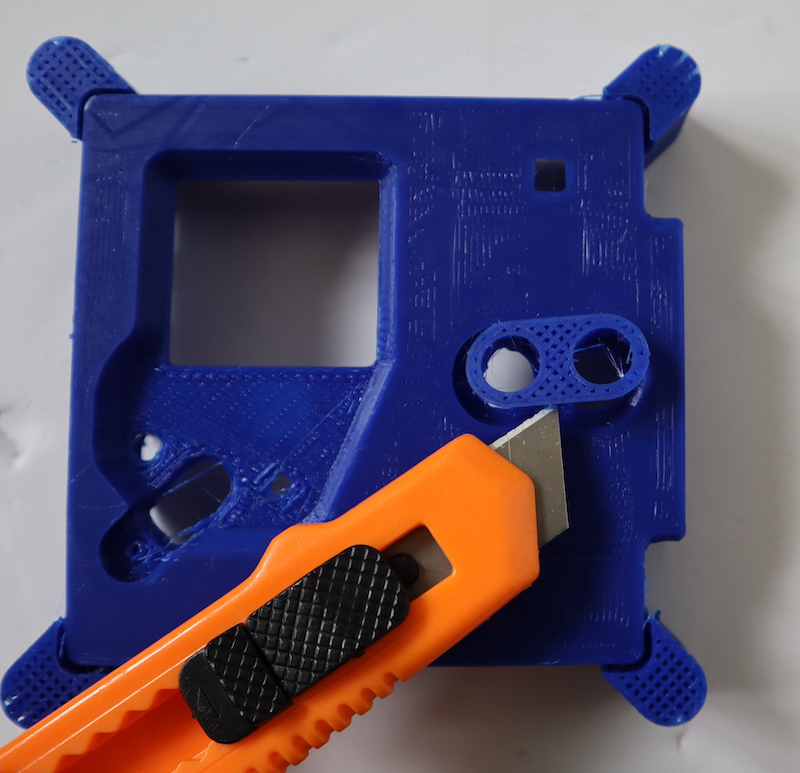
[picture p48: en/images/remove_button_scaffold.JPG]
Photo showing the scaffolding from beneath the buttons being peeled off.


--- /task ---

--- task ---

Finally, tackle the scaffold pieces on the corners. You may need a pair of small pliers to get a strong enough grip, but then the scaffold should just snap off cleanly.  

Photo showing the scaffolding at the corners being griped with pliers.

Close-up photo showing the scaffolding from the corners being snapped off using pliers.

--- /task ---

### Flight Case base

--- task ---

If you've printed this part with a raft, you should be able to separate the raft from the base and carefully peel the raft away so that it also takes the scaffolding with it. Do this very carefully to prevent the individual fins of the heatsink from breaking away. If you do accidentally break one off, it is normally possible to re-attach it with superglue, rather than re-printing the whole panel. 

Photo of the blue 3D-printed base part, showing the raft after it has been removed.

--- /task ---

If you didn't use a raft, then you will need to peel away the scaffolding in sections.

--- task ---
Start with the High-Quality Camera slot:  carefully use a craft knife or scalpel to split the sides of the scaffold filling the recess.

A photo showing a craft knife being used to free the blue 3D-printed camera recess scaffolding.

--- /task ---

--- task ---
A small flat-head screwdriver can be used to start to lift one edge of the scaffold.

A photo showing the blue 3D-printed camera recess scaffolding being levered up with a screwdriver.

--- /task ---

--- task ---
The scaffolding should come away easily if you peel it with your fingers. 

A photo showing a hand peeling off the blue 3D-printed camera recess scaffolding.

--- /task ---

--- task ---

Then clear the material around the SD card slot; this can be done easily using a small screwdriver.

Photo showing a screwdriver blade being used to clear the SD card slot.

--- /task ---

--- task ---

Finally, the base scaffolding should come away easily if you remove it in sections. Before you start, carefully use a craft knife or scalpel to split the sides of the fins away from the scaffold.  

Photo of the blue 3D-printed base part, showing a craft knife blade being used to separate the scaffolding from a heat sink fin.

You can also use a narrow flat screwdriver as a lever to free the scaffold from the case itself. It should require little force; be careful not to snap off any of the fins.

Photo of the blue 3D-printed base part, showing a screwdriver blade being used to lever the scaffolding from the edge.
--- /task ---

--- task ---
Once you've cut the scaffold into sections and have severed each piece from the rest and from the base, carefully slip the scaffolding off the fins. You can use a craft knife to cut the scaffolding into sections for easy removal in stages. 
--- /task ---

Photo of the blue 3D-printed base part with all but one section of the scaffolding removed.

### High-Quality Camera mount

--- task ---

A photo showing a grey, printed High-Quality Camera mount on a raft.

If you used a raft, the scaffolding should come away easily as you peel off the raft with your fingers. 

A photo showing fingers peeling off the blue 3D-printed camera recess scaffolding.

--- /task ---

### Light sensor window

--- task ---

The small piece of support material should easily break away from the window. You may need to remove some additional material from the hole. 

A photo showing a green 3D-printed light sensor window along with the scaffolding on the raft that it was printed on.

--- /task ---

### Joystick cap

--- task ---

Depending on your printer, you may wish to print this part on a raft. Because it is small, it is prone to warping due to contact with the heated print bed.

A photo showing an orange 3D-printed joystick cap along with the raft that it was printed on.

--- /task ---

### Legs

--- task ---

Because this part lacks any flat surfaces, it will need to be printed on a support. 

A photo showing a grey leg and the scaffold support that it was printed on.

This should easily peel away. You may need to use sand paper to smooth the curved surfaces of these legs. 

A photo showing a grey leg and the scaffold being peeled away with pliers.

--- /task ---

## Do a fit check

--- task ---
Before proceeding, put all the pieces together to check that they fit correctly. The lipped edge between the base and top pieces is of most concern to you here. The camera mount needs to fit snugly into the base.

Fit the case together.

Don't worry about any imperfections or residue from the scaffolding at this stage; you can tidy this up later with sandpaper.
--- /task ---

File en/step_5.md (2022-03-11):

## Install the camera

When you're happy with the 3D-printed parts, you can proceed to the hardware installation.

--- task ---
First, lift the two tabs on either side of the High-Quality Camera (HQC) to re-connect the ribbon cable from the camera.
--- /task ---

--- task ---

Second, remove the tripod mount from the HQC sensor by unscrewing the two bolts that attach it. You'll need a 1.5mm allen key for this task. 

--- /task ---

--- task ---
Next, unscrew the two 1.5mm hex lock keys on the underside of the main circuit board. Be careful not to let the washers roll away. There is a gasket of a slightly sticky material between the housing and Printed Circuit Board (PCB), which will require some force to separate.

Lift up the board and place it face up on a very clean surface. Make sure the sensor (the small square in the middle) does not touch the surface.

Photo showing the disassembled Raspberry Pi HQC.

--- /task ---

--- task ---

Slide your 3D-printed camera mount part around the black metal surround of the HQC sensor. Secure it in place by lining up the holes in the bottom lip of the 3D-printed part with the holes for the tripod mount. Attach using two M2 x 5mm screws (note you cannot use the original screws that held the tripod mount in place as they are too long).

Photo showing the Raspberry Pi HQC being attached to the 3D-printed mount using an allen key.

--- /task ---

--- task ---
Replace the main housing over the circuit board. Be sure to realign the housing with the gasket, which remains on the circuit board.

[Photo showing the Raspberry Pi HQC PCB aligned back on the mount.](images/HQC_no_screws.jpg)

The nylon washer prevents damage to the circuit board; apply this washer first. Next, fit the steel washer, which prevents damage to the nylon washer.

Screw down the two hex lock keys. As long as the washers have been fitted in the correct order, they do not need to be screwed very tightly.

Photo showing a screw being re-inserted through the HQC PCB into the mount.
--- /task ---

--- task ---

Now, lift the two tabs on either side of the High-Quality Camera to re-connect the ribbon cable from the camera. Note the blue side of the cable should be facing upwards, away from the PCB as shown. 

Photo showing the correct orientation of the camera cable inserted into the camera sensor.

--- /task ---

--- task ---

Slip the cable through the slit in the base. Make sure you have the correct orientation so that the blue side will face the bottom of the case when folded.

Photo showing the correct orientation of the camera cable when the sensor and mount are being fitted into the case base.

--- /task ---

--- task ---
Slot the camera mount into place. It will be a tight fit, so make sure that any excess scaffolding has been removed from the part itself and from the cavity in the larger case part in which it sits.

Photo showing the camera mount fitted into the case base.

--- /task ---

--- task ---
Fold the ribbon and lay it flat along the inside of the base part. Secure it with a small piece of tape as shown. We have used Kapton tape, but any kind of tape will work fine.

Photo showing the folding and taping of the camera cable in the base.
--- /task ---

--- task ---

Use M2 × 16 screws and M2 nuts to secure the camera mount to the base. The nuts should be on the inside of the case. 

Photo showing the HQC mount secured using four screws and nuts (inside case).

Photo showing the HQC mount secured using four screws and nuts (outside case).
--- /task ---

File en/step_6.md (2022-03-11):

## Install the Raspberry Pi 4 

--- task ---

First, ensure there's no residual scaffolding material around the SD card slot or LED holes that might prevent the Raspberry Pi from lining up with the mounting pillars.

--- /task ---

--- task ---

Once you're happy, line the Raspberry Pi up and do a fit check.  Don't insert the camera ribbon cable just yet.

--- /task ---

--- task ---

Next, screw the M2.5 11mm spacer stand-offs into each corner of the Raspberry Pi. With some light finger pressure, they will cut their own thread in the support pillar pilot holes.

Photo showing the Raspberry Pi in the bottom case part, with a spacer screwed in to the top-left corner mounting hole.

After a few turns, you'll need to use a small pair of pliers or a nut-driver to continue turning them. Try to get the stand-offs to go into the support pillars straight down, and not at a slight angle, because that can lead to alignment issues with the Sense HAT later on. Be careful while you do this and, again, stop turning as soon as the stand-off touches the Raspberry Pi to avoid splitting the pillars horizontally along the grain of the print.

Photo showing a nut-driver being used to screw a spacer into place through the mounting hole in the Raspberry Pi PCB.

If you are having trouble screwing in the stand-offs, screw one of the silver M2.5 cross-head screws into the stand-off, then use the screw head to screw the stand-off into the case. Once the stand-off is in place, don't forget to remove the screw.

--- /task ---

--- task ---

You can now insert the camera ribbon cable into the CSI (Camera Serial Interface) port of the Raspberry Pi. 

Photo showing the Raspberry Pi in the bottom case part, with the camera cable inserted.

--- /task ---

### Install stand-offs for the Sense HAT

The Astro Pi Flight Units onboard the ISS have another custom circuit board in between the Raspberry Pi and Sense HAT; this board holds a real-time clock with backup battery. This mezzanine board also has some pins to allow easy connection to the push buttons and the PIR sensor. Unfortunately, the board is not mass-produced and so is unavailable to the public.

3D cutaway diagram of a Flight Unit, showing the mezzanine board.

Instead, you can use another level of spacers to support the Sense HAT at the correct height.

--- task ---

Add an M2.5 x 10mm spacer to each of the 11mm spacers already installed 

Photo showing the stack of two spacers.

--- /task ---

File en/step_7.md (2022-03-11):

## Solder and install the push buttons

We have created two different front panel options to accommodate two popular sizes of buttons. Most of the photos show the shiny APEM SPDT Momentary Push Buttons as used on the ISS Flight Units. However, you can use any similar button as long as it has the correct thread for the version of the Flight Case that you have printed. You may need to adapt the tasks in this section to reflect the buttons you have chosen.

### Solder the button wires

First, you need to prepare the button wires to be able to attach them to the buttons. In the real Flight Unit, we soldered the button wires on to make them more reliable. This is the most straightforward method, but you could also use connectors if you desire a less permanent solution. The colour of the wires is not important, as they are all exactly the same inside.

Photo showing the components used in this step: wires, buttons, and heat shrink tubing.

--- task ---

Take a coloured wire and remove the black plastic sheath from **one** end. If your wire has a one pointy (M) end, and one end with a hole (F), you should remove the M end connector. You can do this by pulling it off with pliers, or by cutting the wire just below the connector. Strip back approximately 1cm of the insulating sheath from your wire. Repeat this for three additional wires. 

Photo showing a jumper wire with the M connector removed.

--- /task ---

--- task ---

The APEM buttons have three terminals. You're going to connect wires to only two of these, but they need to be the correct ones. The switch between the terminals labelled 1 and 3 is closed when the button is pressed, and these are the terminals to which you should connect your wires.

Photo showing an APEM button with terminals 1 and 3 indicated by a red arrows.

--- /task ---

--- task ---

Twist the exposed copper wires so that all the individual strands are tightly entwined. Then thread the end through a small (1cm long) piece of heat shrink tubing. 

Photo showing a partially stripped wire with with a 1cm piece of red heat shrink tubing slipped over it.

--- /task ---

--- task ---

Secure a button using a vice, a set of "helping hands" (not attached to a human), or just a blob of sticky tack, to hold it steady while you solder.

Thread a wire through one of the correct terminals (see above) and loop it over as shown below. Carefully [solder](https://www.raspberrypi.com/news/getting-started-soldering/) the wire to the terminal. 

Before the solder cools and hardens, pull the wire gently upwards so that it is pointing straight up. This will make it much easier to slide the heat shrink tubing down.

Photo showing a wire soldered to one terminal of a button.

--- /task ---

--- task ---

Slide the heat shrink tubing down over the terminal. Make sure any loose strands of wire are tucked up under sleeve to prevent accidental shorting of the buttons. 

Photo showing a soldered wire with the heat shrink tubing pulled down over the button terminal.

--- /task ---

--- task ---

Now repeat these steps for the second terminal, and then for the second button.

Photo showing the second button with wire soldered to the second terminal.

--- /task ---

--- task ---

Use a heat gun to soften and shrink the heat shrink tubing. 

Photo showing both wires soldered and the terminal and exposed copper sheathed in heat shrink tubing.

--- /task ---

--- task ---

If you are using different buttons, the process should be the same, although you will possibly have only two terminals on the button. 

Photo showing a smaller button with a wire soldered to its terminal.

Use heat shrink tubing to protect the contacts in the same way.

Photo showing a small button with one wire soldered and the terminal and exposed copper sheathed in heat shrink tubing.

--- /task ---

--- task ---

Once you have soldered all the button wires, use a heat gun to shrink the heat shrink tubing, making sure any loose strands of wire are tucked under the tubing and not able to create a short circuit between the terminals. 

Photo showing a heat gun being used on the heat shrink tubing.

--- /task ---

### Install the buttons into the front panel

Most buttons suitable for the Flight Unit will have a locking nut that holds them in place. 

The description below is for the APEM buttons but it should be similar for most other compatible choices. The APEM buttons came with four different fastenings.

--- task ---

Take a button, then unscrew and remove all the nuts and washers. The picture below shows the fastenings next to numbers, which will be used to identify each one in the steps below. 

Photo showing the fastenings for the APEM button, numbered from 1 to 4.

--- /task ---

--- task ---

Put the locking clip (3) back on first, followed by the hexagonal locking nut (1). You can discard the gripping ring (4).

Photo showing an APEM button with both internal fastenings screwed on.

--- /task ---

--- task ---

Slide the button through the hole in the front panel. Secure it with the circular locking ring (2). 

Photo showing an APEM button attached to the Flight Case front panel.

--- /task ---

--- task ---

Repeat the steps above with the second button. 

Photo showing a smaller button attached to the Flight Case front panel.
--- /task ---

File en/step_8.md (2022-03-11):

## Install the PIR sensor

There are two different steps to follow here, depending on which PIR sensor you are using. You should have printed the correct Flight Case front panel to go with your choice of PIR sensor.

### Option 1: Kemet PIR sensor

This is the small, square PIR sensor used on the ISS Astro Pis. It requires a specific matching cable, which needs to be modified to allow connection to the Raspberry Pi's GPIO pins. 

The sensor has an unusual five-pin JST-type connector and requires a matching cable: this cable has five individual strands of wire. Unfortunately, there is no easy way to use this connector directly with the Raspberry Pi GPIO pins. The Flight Units on the ISS have dedicated header pins on the mezzanine board to enable this connection. 

Photo showing the KEMET PIR sensor and cable.

One option is to remove the connector for one end of the cable and solder the bare wire to another wire with an F Dupont connector at the other end. However, the cable's individual wires are very fine and this is not an easy task, and damage to the expensive cable is likely. A less risky method is described below.

--- task ---

Cut the connecter off of one end of the PIR cable.

--- /task ---

--- task ---

Only three of the individual wire strands are needed, so snip off the two redundant ones. Make sure you have correctly oriented the PIR sensor and that you only cut the strands that are not needed (shown in red below). 

Labelled photo indicating that the second and third wires from the left, when looking at the back of the PIR sensor PCB, should be cut.

--- /task ---

--- task ---

Trim the remaining wires by 30mm. Then, carefully strip about 7–10mm of insulation from the end of each strand. 

Photo of a PIR wire strand with 7mm of insulation stripped from the end.

--- /task ---

--- task ---

Cut a three-segment block from an electrical terminal connector strip and insert the bare wire ends of each strand into separate blocks. Tighten the screws and make sure the wires are securely fastened. 

Photo of the PIR cable connected to a three-segment electrical connector block.

--- /task ---

--- task ---

Connect three individual M-F Dupont jumper wires to the other side of the connector block. You should be able to screw down onto the pointy bit of the M end of each wire.

Once you've connected the PIR sensor itself, your complete assembly should look like this:

Photo of a PIR connected via a connector block to three Dupont wires.

--- /task ---

--- task ---

Insert the PIR sensor into the hole in the front panel of the Flight Case and fix it in place by using two M2.5 × 3mm screws. You may need to remove any excess melted filament from the holes first.  

Photo showing the finished installation of the Kemet PIR sensor, front view.

--- /task ---

--- task ---
Place the PIR cable to the left of the pair of buttons. 

--- /task ---

Photo showing the finished installation of the Kemet PIR sensor, back view with the sensor wire positioned as described.

### Option 2: Parallax PIR sensor

This is the domed PIR sensor that is supplied in the Mission Space Lab kits.

--- task ---

Connect three individual M-F Dupont jumper wires to the pins on the back of the PIR sensor PCB. 

Photo of the rear of the Parallax PIR sensor connected with three Dupont wires.

--- /task ---

--- task ---

Feed the wires through the slot in the top-right corner of the Flight Case front panel. 

Photo of the rear of the Flight Case front panel with three Dupont wires fed through the slot.

--- /task ---

--- task ---

Flip the Flight Case front panel over and seat the PIR in the rectangular slot in the top-right corner. Secure with two M2.5 × 6mm screws. You may need to remove any excess melted filament from the holes first.  

Photo of the front of the Flight Case front panel with the Parallax PIR sensor secured with two screws.

--- /task ---

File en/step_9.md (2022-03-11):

## Connect internal wiring to the Raspberry Pi

As previously mentioned, the ISS Astro Pis have an additional PCB to provide connection points for the buttons and PIR sensor. As this custom board is not available commercially, you will need a different approach.

Fortunately, the [Raspberry Pi Sense HAT only uses GPIO pins](https://pinout.xyz/pinout/sense_hat) from the first 24 on the header. This allows us to use a 26 pin header extender to mount the Sense HAT, leaving the remaining 16 pins free.

However, we still need a 3V3 pin for the PIR sensor. Of the two 3V3 pins available, only pin number 1 is actually used by the Sense HAT, so we can use pin number 17.

GPIO diagram.
GPIO-Pinout-Diagram-2.png

--- task ---

Take the 26-pin tall header and carefully use radio pliers to bend the ninth pin on one side through 90 degrees. 

Photo of the tall header with a bent pin.

--- /task ---

--- task ---

Place the top and bottom halves of the Flight Case side by side and connect the button wires to the GPIO pins. One wire from each button should go to a ground pin, the other to a numbered GPIO pin. You can use whichever combination you like, but we recommend:

| Wire  |  GPIO pin | Physical pin number
|---|---|---|
| Button A  |  20 | 38 |
| Button A  | | 34 |
| Button B  |  21 | 40 |
| Button B  | | 30|

Photo of two case halves with button wires connected (Kemet PIR sensor).

Photo of two case halves with button wires connected (Parallax PIR sensor).

--- /task ---

--- task ---
Do the same thing with the ground pin and signal wires from the PIR sensor.

| Wire  |  GPIO pin | Physical pin number
|---|---|---|
| Ground | | 39 |
| Signal/Out | 26  | 37 |

Photo of two case halves with button and two PIR wires connected (Kemet PIR sensor).

Photo of two case halves with button wires connected (Parallax PIR sensor).

--- /task ---

## Install the Sense HAT

--- task ---

Remove the GPIO connector that comes with the Sense HAT. You can wiggle it from side to side, and it will come off without too much force.

The header being removed from the Sense HAT.

--- /task ---

--- task ---
Insert the header into the Sense HAT, through physical pins 1–26 as shown. Make sure the bent pin is facing inwards, underneath the PCB.

Photo of a Sense HAT with the 26-pin tall header inserted.  

Note that the header pins should not protrude through the top of the Sense HAT. If they do, then the height is not correct.

Photo of a Sense HAT with the 26-pin tall header inserted.

--- /task ---

--- task ---

Connect the remaining 3V3 wire from the PIR sensor to the bent pin on the header.

Photo of a Sense HAT with the PIR wire connected to the bent pin.

--- /task ---

--- task ---

Seat the Sense HAT onto the Raspberry Pi. Make sure the orientation is as shown below. Be careful to align both rows of pins with both rows of holes in the header.

Photo of a Sense HAT seated on the Raspberry Pi.
Photo of a Sense HAT seated on the Raspberry Pi.

--- /task ---

--- task ---

Fix the Sense HAT in place with four M2.5 × 6mm screws.

Photo of a Sense HAT seated on the Raspberry Pi with screws.

--- /task ---

--- task ---

To check that the Sense HAT is connected correctly, at this stage it is a good idea to insert a bootable SD card into the Raspberry Pi and connect the USB-C power cable.

You should see the Sense HAT display a rainbow pattern for a few seconds. 

Photo of a Sense HAT displaying the rainbow pattern.

If you have an Astro Pi Mission Space Lab kit and you are using the SD card supplied with it, the rainbow pattern on the LED matrix should disappear a few seconds after you turn the Astro Pi on.

If you're using your own SD card and an original Sense HAT (without the light sensor), there will also be a bright white flash from the LEDs when power is first applied. Also, the rainbow pattern on the LED matrix may remain visible after you turn the Astro Pi on.    

If the rainbow pattern does not disappear once the Raspberry Pi has finished booting, add the following line to the end of the /boot/config.txt file and then reboot.

`dtoverlay=rpi-sense`

--- /task ---

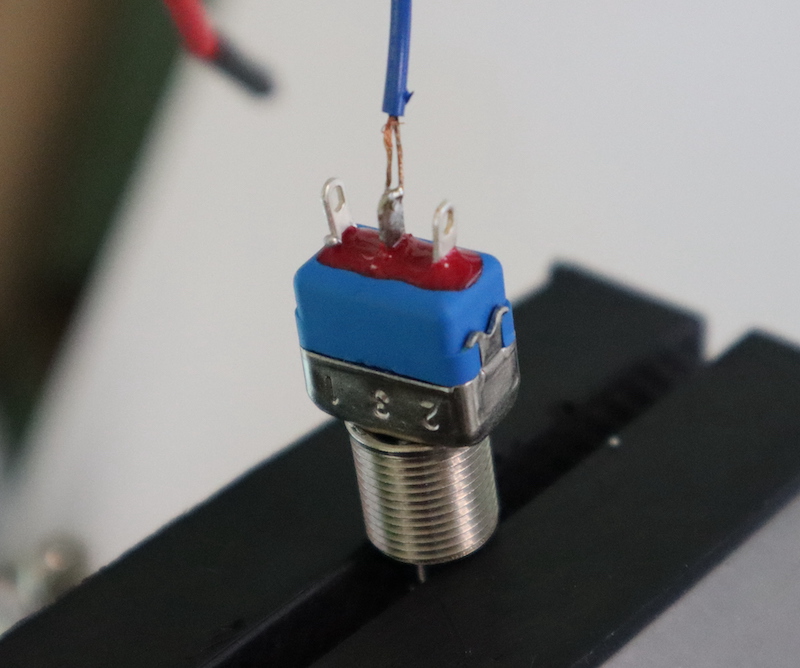
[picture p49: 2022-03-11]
en/images/buttons_solder.JPG

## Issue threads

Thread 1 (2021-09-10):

Unable to process Get the 3D files content

raspberrypilearningbot, 2021-09-10:
There is a markdown issue in step Get the 3D files in locale: en. Error: Markdown contained an unclosed tag: ["task"]

Closed 2022-01-07.

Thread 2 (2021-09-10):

Unable to process Get the 3D files content

raspberrypilearningbot, 2021-09-10:
There is a markdown issue in step Get the 3D files in locale: en. Error: Markdown contained an unclosed tag: ["task"]

Closed 2022-01-07.

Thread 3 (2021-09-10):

en/step_16.md missing

raspberrypilearningbot, 2021-09-10:
Expected a file or directory at en/step_16.md

Closed 2022-01-07.

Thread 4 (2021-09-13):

en/step_16.md missing

raspberrypilearningbot, 2021-09-13:
Expected a file or directory at en/step_16.md

Closed 2022-01-07.

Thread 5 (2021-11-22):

404 on https://projects.raspberrypi.org/en/projects/astro-pi-flight-case-mk2

orjanv, 2021-11-22:
I assume this is just a placeholder page for the project, not done yet?

orjanv, 2021-11-22:
I'm going to hold a teacher training on Astro Pis in less than two weeks, would be very nice to print the new model before then. Any chance I can access the .stl-files, if ready? I don't need the full project page. Thanks in advance.

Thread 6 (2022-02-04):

Unable to process Introduction content

raspberrypilearningbot, 2022-02-04:
There is a markdown issue in step Introduction in locale: en. Error: Markdown contained an unclosed tag: ["no-print"]

Closed 2022-02-04.

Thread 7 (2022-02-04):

Unable to process Introduction content

raspberrypilearningbot, 2022-02-04:
There is a markdown issue in step Introduction in locale: en. Error: Markdown contained an unclosed tag: ["no-print"]

Closed 2022-02-04.

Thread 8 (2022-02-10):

Broken meta.yml

raspberrypilearningbot, 2022-02-10:
Couldn't parse the `meta.yml` file in `en` on `draft` branch.

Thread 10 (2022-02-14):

Broken meta.yml

raspberrypilearningbot, 2022-02-14:
Couldn't parse the `meta.yml` file in `en` on `draft` branch.

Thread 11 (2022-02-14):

Broken meta.yml

raspberrypilearningbot, 2022-02-14:
Couldn't parse the `meta.yml` file in `en` on `draft` branch.

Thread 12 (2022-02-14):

Broken meta.yml

raspberrypilearningbot, 2022-02-14:
Couldn't parse the `meta.yml` file in `en` on `draft` branch.

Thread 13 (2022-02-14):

Broken meta.yml

raspberrypilearningbot, 2022-02-14:
Couldn't parse the `meta.yml` file in `en` on `draft` branch.

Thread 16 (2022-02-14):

Broken meta.yml

raspberrypilearningbot, 2022-02-14:
Couldn't parse the `meta.yml` file in `en` on `draft` branch.

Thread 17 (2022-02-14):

Broken meta.yml

raspberrypilearningbot, 2022-02-14:
Couldn't parse the `meta.yml` file in `en` on `draft` branch.

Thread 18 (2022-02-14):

Broken meta.yml

raspberrypilearningbot, 2022-02-14:
Couldn't parse the `meta.yml` file in `en` on `draft` branch.

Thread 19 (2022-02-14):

Broken meta.yml

raspberrypilearningbot, 2022-02-14:
Couldn't parse the `meta.yml` file in `en` on `draft` branch.

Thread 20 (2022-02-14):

Broken meta.yml

raspberrypilearningbot, 2022-02-14:
Couldn't parse the `meta.yml` file in `en` on `draft` branch.

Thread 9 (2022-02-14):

Broken meta.yml

raspberrypilearningbot, 2022-02-14:
Couldn't parse the `meta.yml` file in `en` on `draft` branch.

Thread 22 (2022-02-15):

Broken meta.yml

raspberrypilearningbot, 2022-02-15:
Couldn't parse the `meta.yml` file in `en` on `draft` branch.

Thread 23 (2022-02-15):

Broken meta.yml

raspberrypilearningbot, 2022-02-15:
Couldn't parse the `meta.yml` file in `en` on `draft` branch.

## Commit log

2021-10-08 new images and text for camera section and other bits
2021-11-15 silver print updates
2021-11-23 added more assembly photos for camera and spacers
2021-12-10 button soldering steps
2021-12-14 finished button step
2022-01-28 joystick cap part
    [Astro_Pi_Mark_II _joystick_cap.stl]
2022-01-31 added legs
    [Astro_Pi_Mark_II_leg.stl]
2022-01-31 leg photos
2022-02-04 double button image
2022-02-16 added leg in cura image
2022-02-18 updated gif
    [Astro_Pi_Mark_II_camera_1.STL, Astro_Pi_Mark_II_upper_kemet_1.STL, Astro_Pi_Mark_II_upper_kemet_small_buttons_1.STL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]
2022-02-24 revised upper parts
    [Astro_Pi_Mark_II_upper_kemet_1.STL, Astro_Pi_Mark_II_upper_kemet_small_buttons_1.STL]
2022-03-11 set correct links to STL files
2022-03-11 fixed joystick filename
    [Astro_Pi_Mark_II_joystick_cap.stl]

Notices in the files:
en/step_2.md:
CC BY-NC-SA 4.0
